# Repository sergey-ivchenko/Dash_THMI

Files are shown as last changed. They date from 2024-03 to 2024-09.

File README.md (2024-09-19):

<h1 align = "center"> Dash_THMI for Civic EF</h1>

Attention: it is not polished. Many parts of code are draft and need to be refactored, but you know how it usually goes once it begin to work.

Project is for VSCode with PlatformIO. 
Arduino framework.

It displays:
- Fuel level (from stock fuel level sensor in tank).
- Coolant temperatue. External additional sensor required 1/8NPT thread. Could be installed in stock place in case of D-series engine. Most likely should be the same for other Honda engine series.
- Oil temperature. External additional sensor required.
- Oil pressure. External additional sensor required. 150psi. 0.5-4.5v
- Fuel pressure. External additional sensor required. 100psi. 0.5-4.5v
- Onboard voltage.

All these values are splitted into 2 screens. Screens could be switched with button.

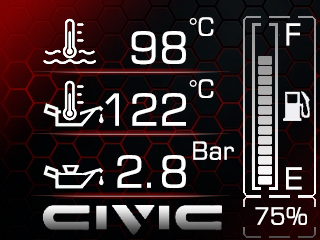
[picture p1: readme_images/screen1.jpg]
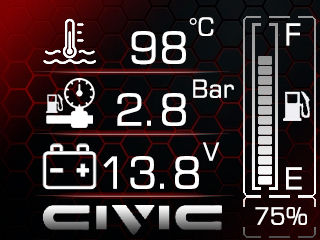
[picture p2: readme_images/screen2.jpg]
 

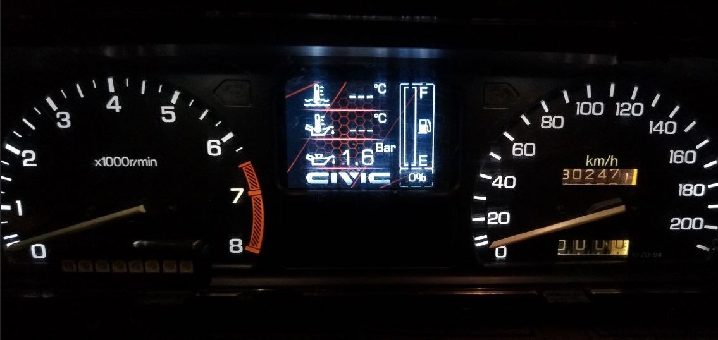
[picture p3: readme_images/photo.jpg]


Sensors I used:
- Temperature - [Aliexpress](https://www.aliexpress.com/item/32841863847.html) (2 Wire Sensor, 1/8 NPT Thread, Temp Range 0°C to 150°C.)
- Pressure - [Aliexpress](https://www.aliexpress.com/item/1005002854614444.html) (3 Wire Sensor, 1/8 NPT Thread, Output signal: 0.5-4.5V)

### Lilygo T-HMI

[Lilygo T-HMI](https://www.lilygo.cc/products/t-hmi) ESP32S3 dev board with 2.8inch display is used as main unit. It fits perfectly into EF's dashboard housing just like it was designed for this.
It stands there upside down.

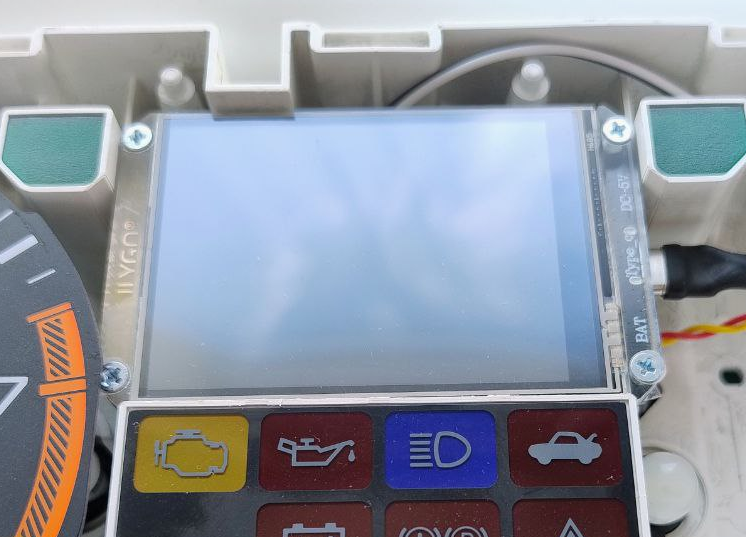
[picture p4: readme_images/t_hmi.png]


However, minor modifications to this board are required due to the tight fitment:
1. Solder out "left" grove connector (when looking at the display upside down)
2. Solder out all buttons
These components slightly protrude beyond the board and prevent the correct installation of the display into the housing.

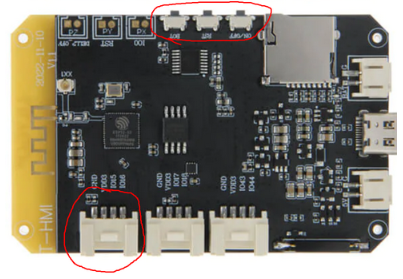
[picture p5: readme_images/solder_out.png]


### PCB

PCB for peripherals and power supply is included in PCB folder (SprintLayout 6 format). 
There is also mirrored PDF version for PCB etching using Laser Printer if you don't have SprintLayout.

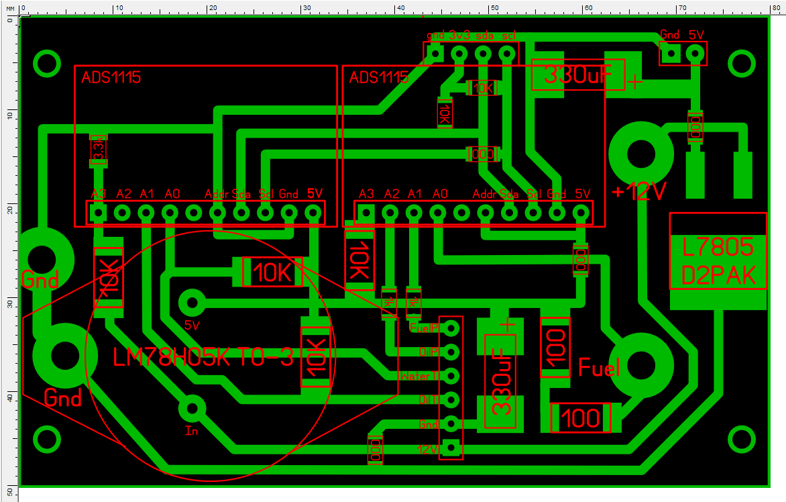
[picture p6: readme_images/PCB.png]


It is recommended to use high precision resistor for voltage dividers. Bigger ones are SMD 2512, smaller are SMD1206.

### ADC

Two external 16bit ADCs are used to make measurements more precise - ADS1115.

Pullup resistors for I2C lines should be removed on both boards because logical levels on ESP32 are 3.3v and ADS1115 power supply is same as sensors pullup - 5V in our case. Pullup to +3.3v is provided on project's PCB.

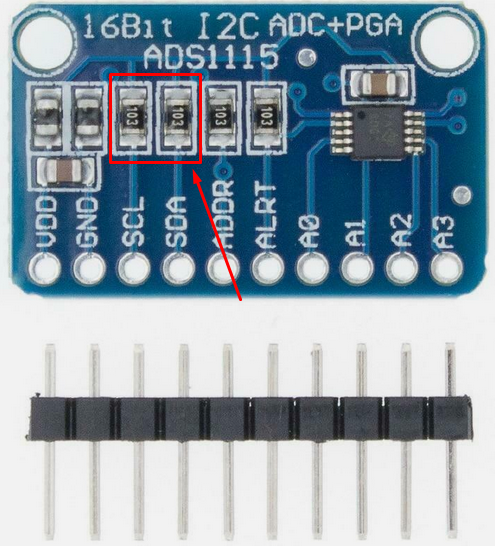
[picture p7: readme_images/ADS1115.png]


### Power Supply

There are separate power supply sources for display and ADCs with resistive sensors pullup.
- LM75H05K in TO-3 for sensors and ADCs
- L7805 in D2PAK for display

### Mounting in the dashboard housing

It utilize standard dashboard housing holes and electric contacts for mounting, power supply and fuel level sensor input.
Other sensors are connected by wires, which come out from the existing hole. 

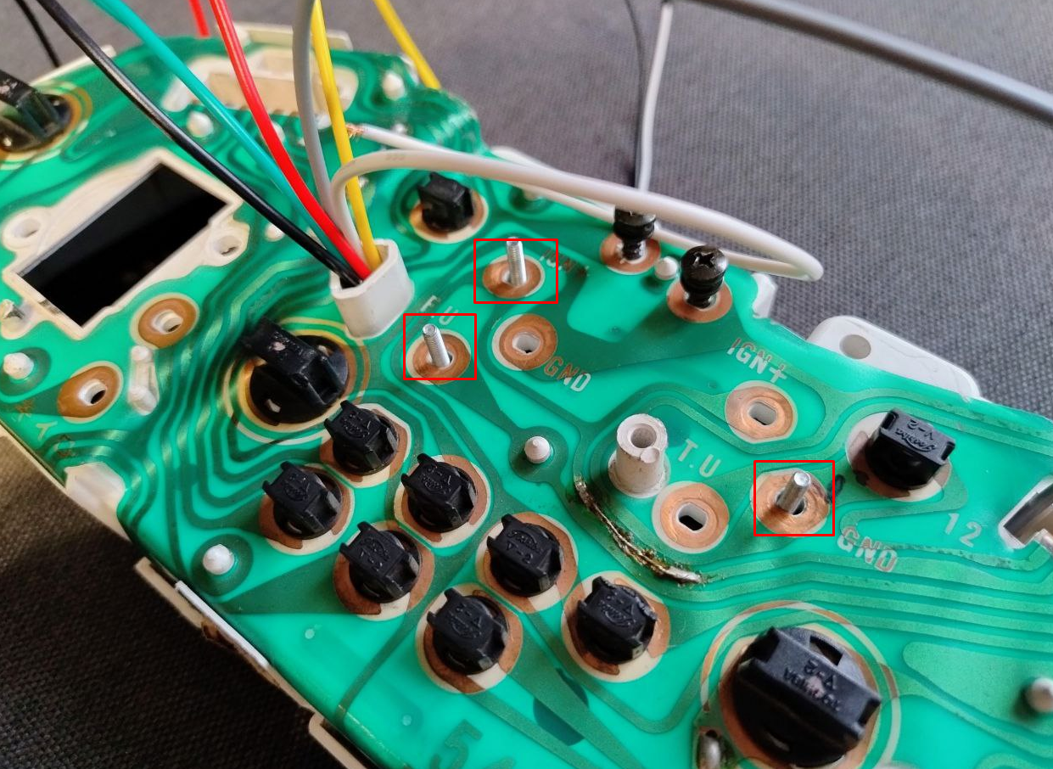
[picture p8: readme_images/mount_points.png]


### Display spacer
There is also a [display spacer model](./DisplaySpacer.stl) available for 3dPrinting. It makes fitment perfect and covers display borders.

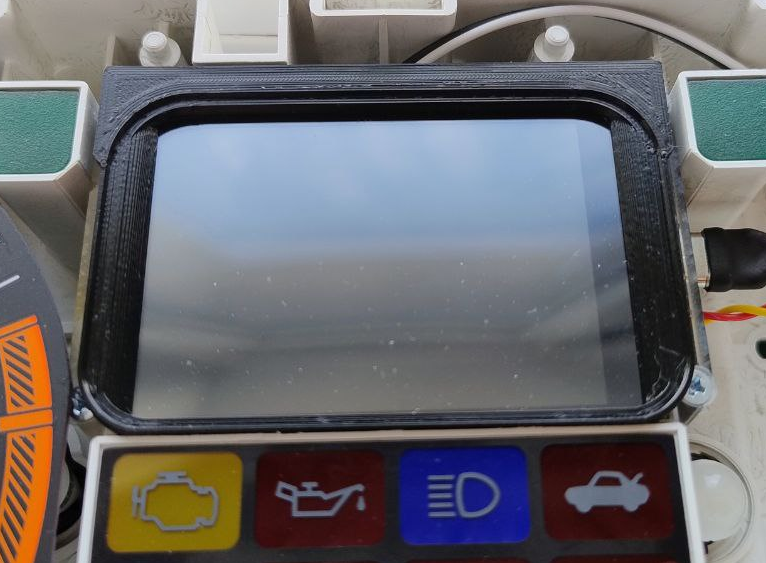
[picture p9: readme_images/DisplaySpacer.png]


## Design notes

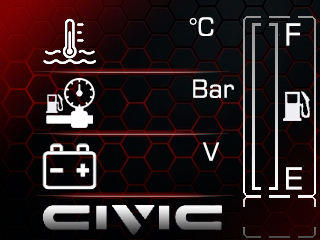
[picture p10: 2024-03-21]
images/bg2.jpg

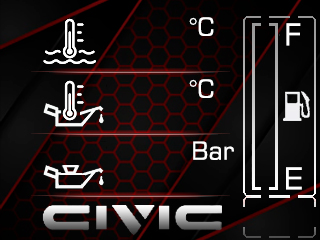
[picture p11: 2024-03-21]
images/bg1.jpg

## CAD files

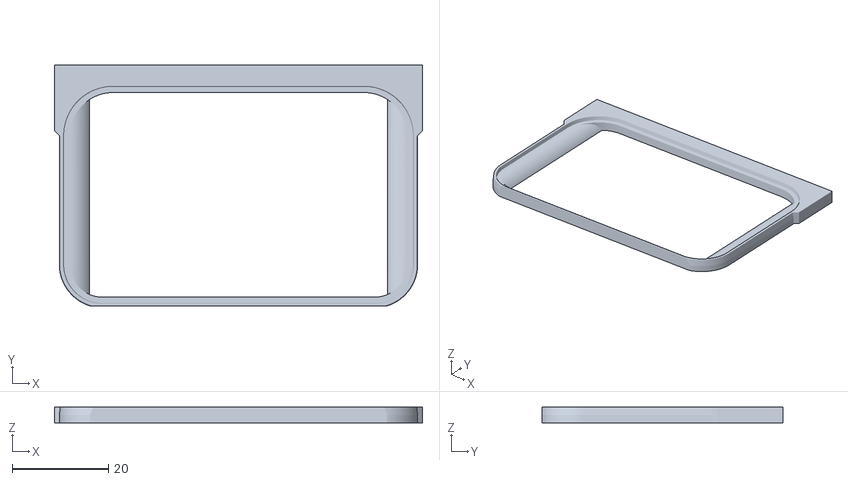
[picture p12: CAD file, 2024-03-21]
DisplaySpacer.stl
76.6 x 50.1 x 3.30

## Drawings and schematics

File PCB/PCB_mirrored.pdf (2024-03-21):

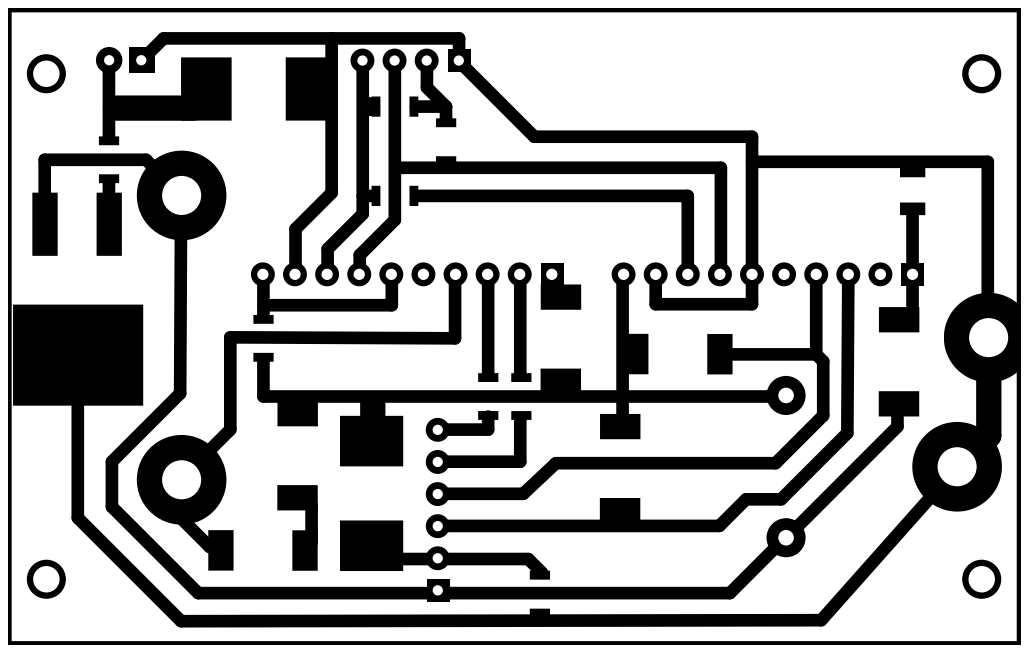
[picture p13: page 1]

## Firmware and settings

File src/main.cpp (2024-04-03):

#include <Arduino.h>
#include <TFT_eSPI.h>
#include <Wire.h>
#include <vector>
#include <EEPROM.h>

#include "pins.h"
#include "Sensors.h"
#include "fonts.h"
#include "bg1.h"
#include "bg2.h"
#include "DrawUtils.h"
#include "WebConfigurator.h"

#define EEP_INIT_ADDR 0
#define EEP_START_ADDR 1
#define EEP_INIT_VAL 55

TFT_eSPI tft = TFT_eSPI();
TFT_eSprite backbuffer = TFT_eSprite(&tft);

enum class Mode : uint8_t
{
    MAIN1 = 0,
    MAIN2,
    DEBUG,
    WiFi
};

Mode mode = Mode::MAIN1;
//------------------------------------------------------------
bool buttonIsDown = false;
u_long buttonDownTimestamp = 0;
const u_long buttonDebugPressTime = 5000;
//------------------------------------------------------------
//Time before warnings are enabled after ignition is turned on.
//This is to avoid low voltage warning when starting the car.
const u_long warningDelayTime = 10000;
u_long startTime = 0;   
//------------------------------------------------------------

bool Blink(uint16_t period)
{
    return millis() % period > (period>>1);
}

void LoadSensorsWarnings()
{
    uint16_t addr = EEP_START_ADDR;
    const uint16_t settingsSize = sizeof(AnalogSensor::WarningSettings);
    for(auto sensor : sensorsWithWarnings)
    {
        EEPROM.readBytes(addr, &(sensor->warningSettings), settingsSize);
        addr += settingsSize;
    }
}

void SaveSensorsWarnings()
{
    uint16_t addr = EEP_START_ADDR;
    const uint16_t settingsSize = sizeof(AnalogSensor::WarningSettings);
    for(auto sensor : sensorsWithWarnings)
    {
        EEPROM.put(addr, sensor->warningSettings);
        addr += settingsSize;
    }
    EEPROM.commit();
}

void InitSensorsWarnings()
{  

    sensorsWithWarnings.push_back(&waterTempSensor);
    sensorsWithWarnings.push_back(&oilTempSensor);
    sensorsWithWarnings.push_back(&oilPressureSensor);
    sensorsWithWarnings.push_back(&fuelPressureSensor);
    sensorsWithWarnings.push_back(&fuelLevelSensor);
    sensorsWithWarnings.push_back(&voltage12v);

    uint16_t eepSize = sensorsWithWarnings.size() * sizeof(AnalogSensor::WarningSettings) + 1;
    EEPROM.begin(eepSize);
    uint8_t initByte = EEPROM.read(EEP_INIT_ADDR);

    if (initByte == EEP_INIT_VAL)
    {
        LoadSensorsWarnings();
    }
    else
    {
        //initialize default warning conditions
        AnalogSensor::WarningSettings ws;
        ws.condition = AnalogSensor::WarningCondition::ABOVE;
        ws.threshold = 105;
        waterTempSensor.SetWarningSettings(ws);

        ws.condition = AnalogSensor::WarningCondition::ABOVE;
        ws.threshold = 120;
        oilTempSensor.SetWarningSettings(ws);

        ws.condition = AnalogSensor::WarningCondition::BELOW;
        ws.threshold = 0.5;
        oilPressureSensor.SetWarningSettings(ws);

        ws.condition = AnalogSensor::WarningCondition::BELOW;
        ws.threshold = 3.0;
        fuelPressureSensor.SetWarningSettings(ws);

        ws.condition = AnalogSensor::WarningCondition::BELOW;
        ws.threshold = 3.0;
        fuelPressureSensor.SetWarningSettings(ws);

        ws.condition = AnalogSensor::WarningCondition::BELOW;
        ws.threshold = 12.5;
        voltage12v.SetWarningSettings(ws);

        EEPROM.write(EEP_INIT_ADDR, EEP_INIT_VAL); //mark EEP as initialized

        SaveSensorsWarnings();
    }

}

void SetBrightness(uint8_t value)
{
    static uint8_t steps = 16;
    static uint8_t _brightness = 0;

    if (_brightness == value) {
        return;
    }

    if (value > 16) {
        value = 16;
    }
    if (value == 0) {
        digitalWrite(BK_LIGHT_PIN, 0);
        delay(3);
        _brightness = 0;
        return;
    }
    if (_brightness == 0) {
        digitalWrite(BK_LIGHT_PIN, 1);
        _brightness = steps;
        delayMicroseconds(30);
    }
    int from = steps - _brightness;
    int to = steps - value;
    int num = (steps + to - from) % steps;
    for (int i = 0; i < num; i++) {
        digitalWrite(BK_LIGHT_PIN, 0);
        digitalWrite(BK_LIGHT_PIN, 1);
    }
    _brightness = value;
}

void ScanI2C()
{
  Wire.begin();
  int nDevices = 0;
  Serial.println("Scanning...");

  for (uint8_t address = 1; address < 127; address++)
  {
    Wire.beginTransmission(address);
    uint8_t error = Wire.endTransmission();
    Serial.println(address, HEX);
    if (error == 0)
    {
      Serial.print("I2C device found at address 0x");
      if (address < 16)
        Serial.print("0");
      Serial.print(address, HEX);
      Serial.println("  !");
      nDevices++;
    }
  }
  if (nDevices == 0)
    Serial.println("No I2C devices found\n");
  else
    Serial.println("done\n");
}

void UpdateSensors()
{
    voltage5v.UpdateSensor();

    fuelLevelSensor.SetPullUpVoltage(voltage5v.Value());
    oilTempSensor.SetPullUpVoltage(voltage5v.Value());
    waterTempSensor.SetPullUpVoltage(voltage5v.Value());

    fuelPressureSensor.UpdateSensor();
    oilPressureSensor.UpdateSensor();
    fuelLevelSensor.UpdateSensor();


    oilTempSensor.UpdateSensor();
    waterTempSensor.UpdateSensor();
    voltage12v.UpdateSensor();

    
}

void InitTft()
{
    tft.begin();
    tft.init();
    tft.setRotation(1);

    backbuffer.createSprite(320, 240);
    backbuffer.setSwapBytes(true);
    SetBrightness(16);
}

void InitI2C()
{
    Wire.setPins(I2C_SDA, I2C_SCL);
    // delay(3000);
    // ScanI2C();

    ads0.begin(0x48);   //addr pin to ground
    ads0.setGain(Gain::TWOTHIRDS_6144MV);
    ads0.setDataRate(Rate::ADS1115_250SPS);

    ads1.begin(0x49);   //addr pin to vcc
    ads1.setGain(Gain::TWOTHIRDS_6144MV);
    ads1.setDataRate(Rate::ADS1115_250SPS);
}

void UpdateWarnings()
{
    if(millis() - startTime < warningDelayTime)
    {
        return;
    }

    bool bHasAnyWarning = oilTempSensor.IsWarning() ||
        waterTempSensor.IsWarning() ||
        voltage12v.IsWarning() ||
        fuelLevelSensor.IsWarning() ||
        fuelPressureSensor.IsWarning() ||
        oilPressureSensor.IsWarning();

    if (mode != Mode::DEBUG && mode != Mode::WiFi && bHasAnyWarning)
    {
        bool blinkState = Blink(1000);
        digitalWrite(PIN_WARNING, blinkState ? HIGH : LOW);
    }
    else
    {
        digitalWrite(PIN_WARNING, LOW);
    }
}

void InitWebConfig()
{
    WebConfInit();
    WebConfOnSave(SaveSensorsWarnings);
    WebConfSetSensors(sensorsWithWarnings);
}

void setup()
{
    startTime = millis();
    Serial.begin(9600);
    pinMode(PIN_BUTTON, INPUT_PULLUP);
    pinMode(PIN_WARNING, OUTPUT);

    pinMode(PWR_EN_PIN, OUTPUT);
    digitalWrite(PWR_EN_PIN, HIGH);

    InitTft();
    InitI2C();
    InitSensorsWarnings();

    UpdateSensors();
    InitWebConfig();
}

void DrawFPS()
{
    static unsigned long lastFrameTime = 0;
    static float avgFrameTime = 0;
    static float FPS = 0;

    unsigned long time = millis();
    uint32_t frameTime = time - lastFrameTime;
    lastFrameTime = time;
    
    avgFrameTime = (avgFrameTime * 9 + frameTime) / 10;
    FPS = 1000/avgFrameTime;

    backbuffer.setTextDatum(TL_DATUM);
    backbuffer.loadFont(font_Arial_16);
    backbuffer.drawString(String(FPS), 16, 16);
}

void DrawMainScreen()
{
    bool blinkRed = Blink(1000) && (millis() - startTime > warningDelayTime);

    backbuffer.setTextColor(TFT_WHITE);
    backbuffer.setTextDatum(TR_DATUM);
    backbuffer.loadFont(font_Square721_44);
    switch (mode)
    {
    case Mode::MAIN1:
        backbuffer.pushImage(0,0, 320, 240, bg1);
        backbuffer.setTextColor(blinkRed && oilTempSensor.IsWarning() ? TFT_RED : TFT_WHITE);
        backbuffer.drawString(oilTempSensor.StrValue(0), 186, 95);

        backbuffer.setTextColor(blinkRed && oilPressureSensor.IsWarning() ? TFT_RED : TFT_WHITE);
        backbuffer.drawString(oilPressureSensor.StrValue(1), 186, 156);
        break;

    case Mode::MAIN2:
        backbuffer.pushImage(0,0, 320, 240, bg2);
        backbuffer.setTextColor(blinkRed && fuelPressureSensor.IsWarning() ? TFT_RED : TFT_WHITE);
        backbuffer.drawString(fuelPressureSensor.StrValue(1), 186, 95);
        
        backbuffer.setTextColor(blinkRed && voltage12v.IsWarning() ? TFT_RED : TFT_WHITE);
        backbuffer.drawString(voltage12v.StrValue(1), 198, 156);
        break;
    
    default:
        break;
    }

    backbuffer.setTextColor(blinkRed && waterTempSensor.IsWarning() ? TFT_RED : TFT_WHITE);
    backbuffer.drawString(waterTempSensor.StrValue(0), 186, 24);

    DrawProgressBar(backbuffer, P_VERTICAL, 257, 183, 16, 155, 
    10, 3, 2,
    (int)fuelLevelSensor.Value(), TFT_WHITE, TFT_DARKGREY);

    backbuffer.loadFont(font_Square721_25);
    backbuffer.setTextDatum(BC_DATUM);
    backbuffer.setTextColor(blinkRed && fuelLevelSensor.IsWarning() ? TFT_RED : TFT_WHITE);
    backbuffer.drawString(fuelLevelSensor.StrValue(0) + "%", 277, 231);
}

void DrawDebugScreen()
{

    const uint16_t x0 = 10;
    const uint16_t x1 = 113;
    const uint16_t x2 = 216;
    uint16_t y = 40;
    uint16_t off = 18;
    backbuffer.fillSprite(TFT_BLACK);

    backbuffer.loadFont(font_Arial_16);
    backbuffer.setTextColor(TFT_WHITE);
    backbuffer.setTextDatum(TL_DATUM);

    backbuffer.drawString("Water temp:", x0, y);
    backbuffer.drawString("Oil Temp:", x1, y);
    backbuffer.drawString("Fuel level:", x2, y);
    y+=off;

    backbuffer.setTextColor(TFT_YELLOW);
    backbuffer.drawString("R:" + waterTempSensor.StrResistance(), x0, y);
    backbuffer.drawString("R:" + oilTempSensor.StrResistance(), x1, y);
    backbuffer.drawString("R:" + fuelLevelSensor.StrResistance(), x2, y);
    y+=off;

    backbuffer.setTextColor(TFT_SILVER);
    backbuffer.drawString(waterTempSensor.StrValueRaw(2) + " *C", x0, y);
    backbuffer.drawString(oilTempSensor.StrValueRaw(2) + " *C", x1, y);
    backbuffer.drawString(fuelLevelSensor.StrValueRaw(2) + " %", x2, y);
    y+=off;

    backbuffer.setTextColor(TFT_GREEN);
    backbuffer.drawString("U: "+ waterTempSensor.StrVoltage() + " V", x0, y);
    backbuffer.drawString("U: "+ oilTempSensor.StrVoltage() + " V", x1, y);
    backbuffer.drawString("U: "+ fuelLevelSensor.StrVoltage() + " V", x2, y);
    y+=off;

    backbuffer.setTextColor(TFT_DARKGREEN);
    backbuffer.drawString("Up:" + waterTempSensor.StrPullUpVoltage() + " V", x0, y);
    backbuffer.drawString("Up:" + oilTempSensor.StrPullUpVoltage() + " V", x1, y);
    backbuffer.drawString("Up:" + fuelLevelSensor.StrPullUpVoltage() + " V", x2, y);
    y+=off;


    y+=off;
    y+=20;

    backbuffer.setTextColor(TFT_WHITE);
    backbuffer.drawString("Fuel Press:", x0, y);
    backbuffer.drawString("Oil Press:", x1, y);
    backbuffer.drawString("Voltage 12:", x2, y);
    y+=off;

    backbuffer.setTextColor(TFT_SILVER);
    backbuffer.drawString(fuelPressureSensor.StrValueRaw(2) + " Bar", x0, y);
    backbuffer.drawString(oilPressureSensor.StrValueRaw(2) + " Bar", x1, y);
    y+=off;

    backbuffer.setTextColor(TFT_GREEN);
    backbuffer.drawString("U: "+ fuelPressureSensor.StrVoltage() + " V", x0, y);
    backbuffer.drawString("U: "+ oilPressureSensor.StrVoltage() + " V", x1, y);
    backbuffer.drawString("U: "+ voltage12v.StrValueRaw() + " V", x2, y);
}

void DrawWiFiScreen()
{
    backbuffer.loadFont(font_Arial_16);
    backbuffer.setTextColor(TFT_WHITE);
    backbuffer.setTextDatum(CC_DATUM);

    backbuffer.fillSprite(TFT_BLACK);
    if(WebConfIsClientConnected())
    {
        backbuffer.drawString("WiFi client is connected", 160, 75);
        backbuffer.drawString("Open 192.168.4.1 in your browser", 160, 100);
        backbuffer.drawString("to configure the dashboard", 160, 125);
    }
    else
    {
        backbuffer.drawString("Listening for Wi-Fi connections", 160, 75);
        backbuffer.drawString("SSID: " + String(web_ssid), 160, 100);
        backbuffer.drawString("Password: " + String(web_password) , 160, 125);
    }
}

void UpdateButton()
{
    if(digitalRead(PIN_BUTTON) == 0)
    {
        if(!buttonIsDown)
        {
            buttonIsDown = true;
            buttonDownTimestamp = millis();
            switch (mode)
            {
            case Mode::MAIN1:
                mode = Mode::MAIN2;
                break;
            case Mode::MAIN2:
                mode = Mode::MAIN1;
                break;
            case Mode::DEBUG:
                mode = Mode::WiFi;
                WebConfStartWiFiAP();
                break;
            case Mode::WiFi:
                mode = Mode::MAIN1;
                WebConfStopWiFiAP();
                break;
            }
        }
        else 
        {
            if(millis() > buttonDebugPressTime + buttonDownTimestamp)
            {
                mode = Mode::DEBUG;
            }
        }
    }
    else
    {
        buttonIsDown = false;
    }
}

void Draw()
{
    {
        switch (mode)
        {
        case Mode::MAIN1:
        case Mode::MAIN2:
            DrawMainScreen();
            break;
        case Mode::DEBUG:
            DrawDebugScreen();
            break;
        case Mode::WiFi:
            DrawWiFiScreen();
            break;
        }
        //DrawFPS();
    }
}

void loop()
{
    UpdateButton();
    if(mode == Mode::WiFi)
    {
        WebConfListenClients();
    }
    else
    {
        UpdateSensors();
        UpdateWarnings();
    }
    Draw();

    backbuffer.pushSprite(0,0);
}

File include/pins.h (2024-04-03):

#pragma once

#define PWR_EN_PIN  (10)
#define PWR_ON_PIN  (14)
#define BAT_ADC_PIN (5)
#define BUTTON1_PIN (0)
#define BUTTON2_PIN (21)
#define PIN_WARNING (17)
#define PIN_BUTTON (18)

#define I2C_SDA (43)
#define I2C_SCL (44)

// lcd
#define LCD_DATA0_PIN (48)
#define LCD_DATA1_PIN (47)
#define LCD_DATA2_PIN (39)
#define LCD_DATA3_PIN (40)
#define LCD_DATA4_PIN (41)
#define LCD_DATA5_PIN (42)
#define LCD_DATA6_PIN (45)
#define LCD_DATA7_PIN (46)
#define PCLK_PIN      (8)
#define CS_PIN        (6)
#define DC_PIN        (7)
#define RST_PIN       (-1)
#define BK_LIGHT_PIN  (38)

// touch screen
#define TOUCHSCREEN_SCLK_PIN (1)
#define TOUCHSCREEN_MISO_PIN (4)
#define TOUCHSCREEN_MOSI_PIN (3)
#define TOUCHSCREEN_CS_PIN   (2)
#define TOUCHSCREEN_IRQ_PIN  (9)

// sd card
#define SD_MISO_PIN (13)
#define SD_MOSI_PIN (11)
#define SD_SCLK_PIN (12)

#define SDIO_DATA0_PIN (13)
#define SDIO_CMD_PIN   (11)
#define SDIO_SCLK_PIN  (12)

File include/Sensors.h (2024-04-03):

#pragma once
#include "AnalogSensor.h"

//-------------Sensors----------------------------------------
using namespace ADS1X15;
//------------------------------------------------------------
const double sensorsPullup = 5.0;
//ads0 sensors
ADS1115<TwoWire> ads0(Wire);//addr 2 gnd

double tempResistance[] = {900,1170, 1510, 1970, 2550, 3320, 4430, 6140, 8610, 12320, 17950, 26650, 40340, 62320};
double tempValues[] = {150, 140, 130, 120, 110, 100, 90, 80, 70, 60, 50, 40, 30, 20};
uint16_t tempLen = 14;

double voltage12VVoltage[] = {0,6};
double voltage12VValues[] = {0,22.78};
uint16_t voltage12VLen = 2;

AnalogSensor waterTempSensor("Water temp",tempResistance, tempValues, tempLen, sensorsPullup, 10000/*Ohm (9900?)*/, 20, &ads0, 0, AnalogSensor::Type::RESISTIVE);
AnalogSensor oilTempSensor("Oil temp",tempResistance, tempValues, tempLen, sensorsPullup, 10000/*Ohm (9900?)*/, 20, &ads0, 1, AnalogSensor::Type::RESISTIVE);
AnalogSensor voltage12v("Voltage", voltage12VVoltage, voltage12VValues, voltage12VLen, -1, -1, 0, &ads0, 3, AnalogSensor::Type::VOLTAGE);
//------------------------------------------------------------
//ads1 sensors
ADS1115<TwoWire> ads1(Wire);

double fuelLevelResistance[] = {5, 32, 110};//stock EF fuel sensor
double fuelLevelValues[] = {100, 50, 0};
uint16_t fuelLevelLen = 3;

double fuelPresVoltage[] = {0.5, 4.5};
double fuelPresValues[] = {0, 6.89};//100psi sensor
uint16_t fuelPresLen = 2;

double oilPresVoltage[] = {0.5, 4.5};
double oilPresValues[] = {0, 10.34};//150psi sensor
uint16_t oilPresLen = 2;

double voltage5VValues[] = {0,6};
uint16_t voltage5VLen = 2;

AnalogSensor fuelLevelSensor("Fuel level", fuelLevelResistance, fuelLevelValues, fuelLevelLen, sensorsPullup, 200/*Ohm*/, 500, &ads1, 0,  AnalogSensor::Type::RESISTIVE);
AnalogSensor fuelPressureSensor("Fuel Pressure", fuelPresVoltage, fuelPresValues, fuelPresLen, -1, -1, 0, &ads1, 1,  AnalogSensor::Type::VOLTAGE);
AnalogSensor oilPressureSensor("Oil Pressure", oilPresVoltage, oilPresValues, oilPresLen, -1, -1, 0, &ads1, 2, AnalogSensor::Type::VOLTAGE);
AnalogSensor voltage5v("Voltage5V", voltage5VValues, voltage5VValues, voltage5VLen, -1, -1, 0, &ads1, 3, AnalogSensor::Type::VOLTAGE);
//------------------------------------------------------------
std::vector<AnalogSensor*> sensorsWithWarnings;
//------------------------------------------------------------

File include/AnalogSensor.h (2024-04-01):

#pragma once
#include <Wire.h>
#include "ADS1X15.h"

class AnalogSensor
{
public:

    enum class Type : uint16_t 
    {
        RESISTIVE = 0,
        VOLTAGE
    };

    enum class WarningCondition : uint8_t 
    {
        NONE = 0,
        BELOW,
        ABOVE,
        
    };

    struct WarningSettings
    {
        WarningCondition condition = WarningCondition::NONE;
        double threshold;
    };

public:
    float pullupResistor = 10000;
    float pullupVoltage = 5;
    uint16_t smoothProbesCount = 10;

    double* inTable = nullptr;
    double* outTable = nullptr;
    uint16_t tableLen = 0;

    double curValue = 0;
    double smoothValue = -999999;
    float curVoltage = 0;

    float curResistance = 45000;
    Type type = Type::RESISTIVE;

    String name;

    ADS1X15::ADS1115<TwoWire>* ads;
    uint8_t channel;

    WarningSettings warningSettings;

    bool bWarningEnabled = true;

private:

    double InterpolateLinear(double xValues[], double yValues[], int numValues, double pointX, bool trim)
    {
        if (trim)
        {
            if (pointX <= xValues[0]) return yValues[0];
            if (pointX >= xValues[numValues - 1]) return yValues[numValues - 1];
        }

        auto i = 0;
        double rst = 0;
        if (pointX <= xValues[0])
        {
            i = 0;
            auto t = (pointX - xValues[i]) / (xValues[i + 1] - xValues[i]);
            rst = yValues[i] * (1 - t) + yValues[i + 1] * t;
        }
        else if (pointX >= xValues[numValues - 1])
        {
            auto t = (pointX - xValues[numValues - 2]) / (xValues[numValues - 1] - xValues[numValues - 2]);
            rst = yValues[numValues - 2] * (1 - t) + yValues[numValues - 1] * t;
        }
        else
        {
            while (pointX >= xValues[i + 1]) i++;
            auto t = (pointX - xValues[i]) / (xValues[i + 1] - xValues[i]);
            rst = yValues[i] * (1 - t) + yValues[i + 1] * t;
        }

        return rst;

    }

public:
    AnalogSensor(String name, double* inTable, double* outTable, uint16_t tableLen, float V, float R, uint16_t smooth, ADS1X15::ADS1115<TwoWire>* ads, uint8_t channel, Type type = Type::RESISTIVE)
    {
        this->name = name;
        this->outTable = outTable;
        this->inTable = inTable;
        this->tableLen = tableLen;
        this->type = type;
        this->ads = ads;
        this->channel = channel;


        pullupResistor = R;
        pullupVoltage = V;
        smoothProbesCount = smooth;
    }

    void UpdateSensor()
    {
        curVoltage = ads->computeVolts(ads->readADCSingleEnded(channel));

        curResistance = pullupResistor * (1/(pullupVoltage/curVoltage - 1));

        if(!outTable || !tableLen)
        {
            curValue = 0;
        }
        else
        {
            double inValue = type==Type::RESISTIVE ? curResistance : curVoltage;
            curValue = InterpolateLinear(inTable, outTable, tableLen, inValue, true);

            //curValue = Interpolation::CatmullSpline(inTable, outTable, tableLen, inValue);
        }

        if(smoothValue < -888888 || smoothProbesCount == 0)
        {
            smoothValue = curValue;
        }
        else
        {
            smoothValue = (smoothValue * smoothProbesCount + curValue)/(smoothProbesCount + 1);
        }
    }

    String StrValue(uint16_t decimals = 2)
    {
        if(type == Type::RESISTIVE && (Resistance() > 1000000 || Resistance() < 1))
            return "---";
        return String(smoothValue, decimals);
    }

    String StrValueRaw(uint16_t decimals = 2)
    {
        if(type == Type::RESISTIVE)
        {
            if(curVoltage >= pullupVoltage - 0.01) 
            {
                return "Open";
            }
            if(curVoltage < 0.01)
            {
                return "Short";
            }
        }
        return String(curValue, decimals);
    }

    String StrVoltage()
    {
        return String(curVoltage,3);
    }

    String StrResistance()
    {
        return String(curResistance, 0);
    }

    String StrPullUpVoltage()
    {
        return String(pullupVoltage, 3);
    }

    String Name()
    {
        return name;
    }

    
    
    float Value()
    {
        return smoothValue;
    }

    float ValueRaw()
    {
        return curValue;
    }

    float Voltage()
    {
        return curVoltage;
    }

    float Resistance()
    {
        return curResistance;
    }

    void SetWarningSettings(const WarningSettings& settings)
    {
        warningSettings = settings;
    }

    bool IsWarning()
    {
        if(!bWarningEnabled)
        {
            return false;
        }
        switch (warningSettings.condition)
        {
        case WarningCondition::ABOVE:
            return smoothValue >= warningSettings.threshold;
        case WarningCondition::BELOW:
            return smoothValue <= warningSettings.threshold;
        default:
            return false;
        }
    }

    void SetPullUpVoltage(float v)
    {
        pullupVoltage = v + 0.003; //increase a bit because of adc tolerance
    }
};

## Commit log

2024-03-14 - connected ADS1115 - adjust graphics to correspond dashboard window - setup sensors
2024-03-15 + added PCB for ADCs, DC-DC converters and all input stuff + added warnings support + added one more ADS1115
2024-03-21 - PCD final version + add display spacer + add second screen + add button handling - code reorganization
    [DisplaySpacer.stl]
2024-03-21 + added PDF PCB for laser printing
2024-03-21 - mark resistors to be removed
2024-03-21 + added mount points photo
2024-03-21 - update spacer image
